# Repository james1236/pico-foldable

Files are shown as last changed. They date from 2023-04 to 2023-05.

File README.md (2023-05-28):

# pico-foldable
A small ds-style foldable Raspberry Pi Pico console with a buzzer, a joystick, a display and some buttons. You can easily make new games as seperate files in [/creations/](./creations) and a game picking menu/autorun system lets you play them (hold both buttons to get to the menu). The 3D printed case prints in 4 main parts and has a print-in-place hinge.

<p>
    
    
    
    
</p>

It is powered by a 3.7v LiPo battery through the adafruit Powerboost 500c recharger/power supply board. The EN (enable) pin on this board allows a circuit across the magnets between both displays to turn the whole device on when opened. A MicroUSB breakout board is installed to direct power to the Powerboost 500c while directing the data lines straight to the Pico's test pads, allowing you to plug it in as usual to upload code or debug.
  
  |  |   |
| ----- | ----- |
|     |  |





Printed using PLA on an Ender 3, 3D model [here](./complete%20pico%20foldable.stl). Inspired by <a href="https://www.youtube.com/watch?v=aZc5gUKcRZA">N-O-D-E</a>

### Parts
|Part|Quantity|
|---|---|
|Raspberry Pi Pico (RP2040)|1|
|Passive Piezo Electric Buzzer|1|
|<a href="https://www.adafruit.com/product/1944">Adafruit Powerboost 500C</a>|1|
|Female MicroUSB Breakout Board|1|
|520-614 Rainbow Ribbon Cable 10 Way (Squires Tools - conductor spacing 0.05in, conductor - 7/0.127mm tin plated copper, 1A 300V per conductor)|1|
|3mm dia x 1mm thick Neodynium magnets with 0.13kg pull|4|
|<a href="https://www.waveshare.com/1.5inch-OLED-Module.htm">1.5inch OLED Display Module, 128x128 Pixels, 16 Gray Scale, SPI/I2C Interface</a>|1|
|<a href="https://www.sparkfun.com/products/9426">Joystick - Sparkfun COM-09426</a>|1|
|Momentary Tactile PCB Push Buttons 6mm x 6mm|2|
|3.7V 500mAh Lipo Lithium Polymer Battery - GPS Drone EHAD702035 (Dimensions approx 37 mm x 21 mm x 8mm) |1|
|500 Ohm Resistor (for reducing buzzer volume)|1|

### Ribbon Cable Wires
|Num|Color|Connection|
|---|---|---|
|1|brown|bat 3.7|
|2|red|GND|
|3|orange|buzzer|
|4|yellow|left button|
|5|green|right button|
|6|blue|joystick X|
|7|purple|joystick Y|
|8|gray|VCC|

### Bottom Half Wires
|Output|Input|
|---|---|
|Magnet|GND (ribbon wire 2)|
|Left Button|GND (ribbon wire 2)|
|Right Button|GND (ribbon wire 2)|
|Joystick GND|GND (ribbon wire 2)|
|Buzzer -|GND (ribbon wire 2)|
|LiPo Battery negative (black) wire|GND (ribbon wire 2)|
|LiPo Battery positive (red) wire|bat 3.7 (ribbon wire 1)|
|Buzzer +|buzzer wire (ribbon wire 3)|
|Left Button (opposite half)|left button wire (ribbon wire 4)|
|Right Button (opposite half)|right button wire (ribbon wire 5)|
|Joystick X|joystick X wire (ribbon wire 6)|
|Joystick Y|joystick Y wire (ribbon wire 7)|
|Joystick VCC|VCC (ribbon wire 8)|

### Top Half Wires
|Output|Input|
|---|---|
|Powerboost 500c EN (enable)|Magnet|
|Powerboost 500c BAT|Battery positive (ribbon wire 1)|
|Powerboost 500c USB|USB Breakout VCC positive|
|Pico pin 28 (GND)|USB Breakout GND negative|
|Pico pin 40 (VBUS)|Powerboost 500c USB positive pad|
|Pico pin 33 (GND)|Powerboost 500c USB negative pad|
|Pico TP2 (Test pad 2)|USB Breakout Data Minus (DM or D-)|
|Pico TP3 (Test pad 3)|USB Breakout Data Plus (DP or D+)|
|Pico pin 13 (GND)|Bottom half GND (ribbon wire 2)|
|Pico pin 1 (GP0)|500 ohm resistor -> buzzer (ribbon wire 3)|
|Pico pin 19 (GP14)|Left button (ribbon wire 4)|
|Pico pin 20 (GP15)|Right button (ribbon wire 5)|
|Pico pin 31 (ADC0)|Joystick X (ribbon wire 6)|
|Pico pin 32 (ADC1)|Joystick Y (ribbon wire 7)|
|Pico pin 39 (VSYS)|VCC (ribbon wire 8)|
|Pico pin 21 (GP16)|Display SDA (DIN)|
|Pico pin 22 (GP17)|Display SCK (CLK)|
|Pico pin 36 (3V3 OUT)|Display VCC|
|Pico pin 18 (GND)|Display GND|

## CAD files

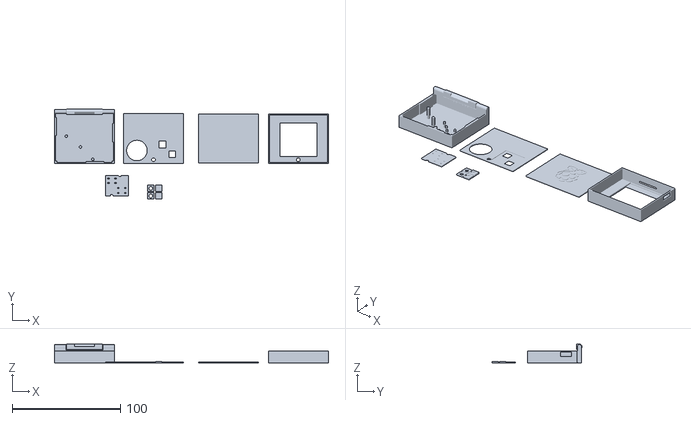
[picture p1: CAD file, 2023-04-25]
complete pico foldable.stl
253.6 x 83.5 x 17.5

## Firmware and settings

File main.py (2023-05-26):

# Initializes display and controls, shows menus
# Put .py files you want to run in /creations/ and they will show up in the menu
# Look at demo.py for an example of how to make a compatible creation

from machine import Pin, I2C, ADC

from time import sleep
import os
 
import framebuf

#TRUE = Throw all errors, crashes
#FALSE = Display errors on the device screen instead and attempt to continue
# Keep true while debugging to get info like line numbers
# Keep false for users so that one bug in a creation doesn't crash the whole device
debug = False

#Stop any previous music PWM
#from buzzer_music import music
#music().stop()


#Display wrapper class - better than display specific draw instructions...
class display:
    def __init__(self, display_type):
        self.display_type = display_type
        self.skippedFrames = 0
        
        if (self.display_type == "SSD1306 Monochrome"):
            width = 128
            height = 64

            #Put the GP pins you use for SDA and SCL here
            i2c = I2C(0,sda=Pin(4),scl=Pin(5),freq=600000) #40000
            from ssd1306 import SSD1306_I2C
            self.oled = SSD1306_I2C(width,height,i2c)

            self.width = self.oled.width
            self.height = self.oled.height
        
        elif (self.display_type == "Pimoroni Pico Display"):
            
            import picodisplay
            
            self.oled = picodisplay
            self.width = self.oled.get_width()
            self.height = self.oled.get_height()
            picodisplay_buffer = bytearray(self.width * self.height * 2)  # 2-bytes per pixel (RGB565)
            self.oled.init(picodisplay_buffer)
            picodisplay_buffer = None
            self.oled.set_backlight(1.0)
            self.fill(0)
            
        elif (self.display_type == "Waveshare SSD1327 16 Bit Grey"):
            
            from ssd1327 import WS_OLED_128X128
            
            oled_i2c = I2C(0, sda=Pin(16), scl=Pin(17),freq=3000000) #2300000
            self.oled = WS_OLED_128X128(oled_i2c, addr=int(hex(oled_i2c.scan()[0])))

            print("OLED I2C Address : " + hex(oled_i2c.scan()[0]).upper()) # Print the I2C device address in the command line
            print("OLED I2C Configuration: " + str(oled_i2c))
            
            self.width = self.oled.width
            self.height = self.oled.height
        
    def fill_rect(self, x, y, width, height, color):
        if (self.display_type == "SSD1306 Monochrome"):
            if (color > 0):
                color = 1
            self.oled.fill_rect(x,y,width,height,color)
            
        elif (self.display_type == "Pimoroni Pico Display"):
            c = round(255*color)
            self.oled.set_pen(c, c, c)
                
            self.oled.rectangle(x,y,width,height)
            
        elif (self.display_type == "Waveshare SSD1327 16 Bit Grey"):
            
            self.oled.fill_rect(x,y,width,height,round(15*color))
            
        else:
            #...since you can add support for other screens
            pass
        
    def show(self):
        if (self.display_type == "SSD1306 Monochrome" or self.display_type == "Waveshare SSD1327 16 Bit Grey"):
            try:
                self.oled.show()
            except OSError as e:
                self.skippedFrames = self.skippedFrames + 1
            
        elif (self.display_type == "Pimoroni Pico Display"):
            self.oled.update()
        
    def fill(self, color):
        if (self.display_type == "SSD1306 Monochrome"):
            if (color > 0):
                color = 1
            self.oled.fill(color)
        
        elif (self.display_type == "Pimoroni Pico Display"):
            c = round(255*color)
            self.oled.set_pen(c, c, c)
            
            self.oled.clear()
            
        elif (self.display_type == "Waveshare SSD1327 16 Bit Grey"):
            self.oled.fill(round(15*color))
            
    def text(self, text, x, y, color=1):
        if (self.display_type == "SSD1306 Monochrome"):
            self.oled.text(text, x, y)
            
        elif (self.display_type == "Pimoroni Pico Display"):
            c = round(255*color)
            self.oled.set_pen(c, c, c)
            
            self.oled.text(text, x, y, 0, 1)
            
        elif (self.display_type == "Waveshare SSD1327 16 Bit Grey"):
            self.oled.text(text, x, y, round(15*color))
    
    def pixel(self, x, y, color):
        if (self.display_type == "SSD1306 Monochrome"):
            if (color > 0):
                color = 1
                
            self.oled.pixel(x, y, color)
        
        elif (self.display_type == "Pimoroni Pico Display"):
            c = round(255*color)
            self.oled.set_pen(c, c, c)
            
            self.oled.pixel(x, y)
            
        elif (self.display_type == "Waveshare SSD1327 16 Bit Grey"):
            self.oled.pixel(x, y, round(15*color))
            
    def blit(self, buffer, x, y, key, palette=None):
        if (self.display_type == "SSD1306 Monochrome"):
            if (key > 0):
                key = 1
            self.oled.blit(buffer, x, y, key)
            
        elif (self.display_type == "Waveshare SSD1327 16 Bit Grey"):
            if (palette == None):
                self.oled.blit(buffer, x, y, round(15*key))
            else:
                self.oled.blit(buffer, x, y, round(15*key), palette)
            
    def line(self, x1, y1, x2, y2, color):
        if (self.display_type == "SSD1306 Monochrome"):
            if (color > 0):
                color = 1
            self.oled.line(x1, y1, x2, y2, color)
            
    def scroll(self, x, y):
        if (self.display_type == "SSD1306 Monochrome" or self.display_type == "Waveshare SSD1327 16 Bit Grey"):
            self.oled.scroll(x, y)

    def invert(self, i):
        self.oled.invert(i)
            
    def stroke_rect(self, x, y, width, height, color):
        if (self.display_type == "SSD1306 Monochrome"):
            if (color > 0):
                color = 1
            self.oled.stroke_rect(x,y,width,height,color)
            
        elif (self.display_type == "Pimoroni Pico Display"):
            c = round(255*color)
            self.oled.set_pen(c, c, c)
                
            self.oled.stroke_rect(x,y,width,height)
            
        elif (self.display_type == "Waveshare SSD1327 16 Bit Grey"):
            
            self.oled.stroke_rect(x,y,width,height,round(15*color))
        #self.fill_rect(0+x,0+y,width,1,color)
        #self.fill_rect(width-1+x,0+y,1,height,color)
        #self.fill_rect(0+x,height-1+y,width,1,color)
        #self.fill_rect(0+x,0+y,1,height,color)

    def ellipse(self, x, y, xr, yr, col, fill=False, quadrantBits=0xF):
        self.oled.ellipse(x, y, xr, yr, round(15*col), fill, quadrantBits)

    def poly(self, x, y, coords, col, fill=False):
        self.oled.poly(x, y, coords, round(15*col), fill)

    def rotate(self, rot):
        self.oled.rotate(rot)

    def contrast(self, c):
        self.oled.contrast(c)
    
    def poweron(self):
        self.oled.poweron()

    def poweroff(self):
        self.oled.poweroff()

#display = display("SSD1306 Monochrome")
#display = display("Pimoroni Pico Display") #WIP
display = display("Waveshare SSD1327 16 Bit Grey")

#Class for creations to use input
class controller:
    def __init__(self, analogs=[], buttons=[], joyscale=1000, deadzone=10, picodisplay=None):
        self.joystick = False
        self.joyscale = joyscale
        self.deadzone = deadzone
        
        if (len(analogs) >= 2):
            #Use analogs as joystick
            self.joyX = analogs[0]
            self.joyY = analogs[1]
            
            self.joystick = True
            self.joyCenter = (self.joyX.read_u16(),self.joyY.read_u16())
            
        self.buttons = buttons
        
        self.usePicodisplay = False
        if (not (picodisplay is None)):
            self.usePicodisplay = True
            self.picodisplay = picodisplay
            
            
    def readJoystick(self):
        if (self.joystick):
            x = self.joyX.read_u16() - self.joyCenter[0]
            y = self.joyY.read_u16() - self.joyCenter[1]
            
            x = x / self.joyscale
            y = y / self.joyscale
            
            outsideDeadzone = False
            if (abs(x) > self.deadzone or abs(y) > self.deadzone):
                outsideDeadzone = True
                
            return (-x, y, outsideDeadzone)
        
        else:
            #Emulate non existant joystick with buttons
            if (not self.readButton(0)):
                return (0, -20, True)
            elif (not self.readButton(1)):
                return (0, 20, True)
            elif (not self.readButton(2)):
                return (-20, 0, True)
            elif (not self.readButton(3)):
                return (20, 0, True)
            
            return (0,0,False)
    
    
    def readButton(self, buttonNumber):
        if (self.usePicodisplay):
            if (buttonNumber == 0):
                if (display.oled.is_pressed(display.oled.BUTTON_A)):
                    return True
                else:
                    return False
            
            elif (buttonNumber == 1):
                if (display.oled.is_pressed(display.oled.BUTTON_B)):
                    return True
                else:
                    return False
                
            elif (buttonNumber == 2):
                if (display.oled.is_pressed(display.oled.BUTTON_X)):
                    return True
                else:
                    return False
                
            elif (buttonNumber == 3):
                if (display.oled.is_pressed(display.oled.BUTTON_Y)):
                    return True
                else:
                    return False
        else:
            if (buttonNumber >= len(self.buttons)):
                return False
            return not self.buttons[buttonNumber].value()

controller = controller(analogs=[
    ADC(Pin(27)),
    ADC(Pin(26))
], buttons=[
    Pin(14, machine.Pin.IN, machine.Pin.PULL_UP),
    Pin(15, machine.Pin.IN, machine.Pin.PULL_UP)
])

#controller = controller(picodisplay=display)


creations = os.listdir('/creations/')

#Remove non .py files from creations array
i = 0
while (i < len(creations)):
    if (not (".py" in creations[i])):
        creations.pop(i)
    else:
        i = i + 1
    
creation = None

mainMenu = True
cursor = 0

frame = 0

names = []
thumbnails = []

#Get name+thumbnail for each creation
i = 0
for filename in creations:
    #Attempt Import
    exec("try:\n    from creations."+creations[i].replace('.py','')+" import description\nexcept ImportError:\n    pass")
    
    try:
        description
    except NameError:
        #Unsuccessful
        names.append(creations[i].replace('.py',''))
        thumbnails.append(None)
    else:
        #Successful
        if (hasattr(description, 'name')):
            names.append(description.name)
        else:
            names.append(creations[i].replace('.py',''))
            
        if (hasattr(description, 'thumbnail')):
            thumbnails.append(framebuf.FrameBuffer(description.thumbnail, 32, 32, framebuf.MONO_HLSB))
        else:
            thumbnails.append(None)
        
        del description
    i = i + 1


#Handle errors thrown by creations so that they can be dropped back to main menu
#Disable by setting debug = True
def errorHan(e, customMessage=None):
    global debug
    global mainMenu
    global creation
    global display
    
    if (debug):
        raise e
        return

    e = repr(e)
    print(e)
    print("Set debug = True in main.py to throw exceptions...")
    print("Skipped frames: " + str(display.skippedFrames))
    
    #Split exception string into screen width strings
    n = int(display.width/8)
    o = []
    while e:
        o.append(e[:n])
        e = e[n:]
    
    display.fill(0)
    for i in range(len(o)):
        display.text(o[i],0,i*8)
        
    if (not (customMessage is None)):
        o = []
        while customMessage:
            o.append(customMessage[:n])
            customMessage = customMessage[n:]
        
        for j in range(len(o)):
            display.text(o[j],0,((i+1)*8)+(j*8))
        
    display.show()
    sleep(5)
    creation = None
    mainMenu = True

#Function to load into the selected creation
def onSelect():
    global creations
    global cursor
    global creation
    global mainMenu
    global display
    global config
    
    print("onSelect")
    
    display.fill(0)
    display.text("Loading %s..." % creations[cursor].replace('.py',''), 0, 0)
    display.show()
    if (controller.readButton(0) == 1 and controller.readButton(1) == 1):
        return
    
    autorunFile = open('autorun', 'w')
    autorunFile.write(str(cursor))
    autorunFile.close()
    
    exec("try:\n    from creations.%s import creation\nexcept Exception:\n    pass" % creations[cursor].replace('.py',''))
    
    mainMenu = False
    try:
        creation = creation(display, controller)
    except Exception as e:
        errorHan(e, "Error while trying to create object from expected 'creation' class in the file")
    
#Try to auto open previous creation
autorunFile = open('autorun', 'r')
c = autorunFile.read()
if (not (c == '')):
    cursor = int(c)
    if (cursor >= len(creations)):
        cursor = len(creations)-1
    onSelect()
autorunFile.close()

moveCooldown = 0

buttonCooldowns = [0,0]
buttonCooldown = 5

heldDown = 0

led = Pin(25, Pin.OUT) #Blink led to show it's alive

display.contrast(255)

while True:
    frame = frame + 1
    led.toggle()
    
    buttonCooldowns[0] = max(0, (buttonCooldowns[0] - 1))
    buttonCooldowns[1] = max(0, (buttonCooldowns[1] - 1))
    
    #Hold down both buttons for 30 frames to exit to main menu
    if (controller.readButton(0) and controller.readButton(1)):
        heldDown = heldDown + 1
        if (heldDown > 30):
            heldDown = 0
            buttonCooldowns[0] = 15
            buttonCooldowns[1] = 15
            print("Skipped frames: " + str(display.skippedFrames))
            
            if (not(creation is None)):
                try:
                    creation.close()
                except Exception:
                    pass
                del creation
                creation = None
            mainMenu = True
            autorunFile = open('autorun', 'w')
            autorunFile.write(str(""))
            autorunFile.close()
                
    else:
        heldDown = 0
    
    if (mainMenu):
        #Move cursor
        if (moveCooldown > 0):
            moveCooldown = moveCooldown - 1
        
        joy = controller.readJoystick()
        if (joy[2] and (moveCooldown <= 0) and (abs(joy[1]) > abs(joy[0]))):
            moveCooldown = 5
            if (joy[1] > 0):
                #up
                cursor = cursor + 1
                if (cursor >= len(creations)):
                    cursor = 0
            else:
                #down
                cursor = cursor - 1
                if (0 > cursor):
                    cursor = len(creations)-1
            
        #Detect button press
        select = False
        if (buttonCooldowns[0] == 0):
            if (controller.readButton(0)):
                buttonCooldowns[0] = buttonCooldown
                select = True
        
        display.fill(0)
        if (not (thumbnails[cursor] is None)):
            for thumbx in range(5):
                for thumby in range(5):
                    #display.blit(thumbnails[cursor],display.width-40,16,0)
                    display.blit(thumbnails[cursor],-32 + thumbx*32 + (frame % 32),-32 + thumby*32 + (frame % 32),0)
        
        #List files in creations folder
        ySpacing = 11
        i = 0
        
        #Calculate scroll position of text
        linesPerScreen = 11
        scroll = 0
        if (len(creations) > linesPerScreen):
            if (cursor > 2):
                scroll = (cursor-2)*ySpacing
                
                #Stop scroll at the bottom
                if ((len(creations)-1) - cursor < 3):
                    scroll = (len(creations)-linesPerScreen)*ySpacing
        
        scroll = 0 - scroll

            
        for i in range(len(creations)):
            display.fill_rect(8,3+(ySpacing*i)-1+scroll,len(names[i])*8+2,ySpacing,0)
            display.text(names[i],9,3+(ySpacing*i)+scroll)
            
            #Selection Border
            if (cursor == i):
                display.stroke_rect(8,3+(ySpacing*i)-1+scroll,len(names[i])*8+2,ySpacing,1)
            
            i = i + 1
        
            
        #Scroll bar
        display.stroke_rect(0,0,4,display.height,1)
        
        position = cursor/max((len(creations)-1),1)
        display.fill_rect(1,round(position*display.height)-round(display.height/8),2,round(display.height/4),1)
                
        display.show()
        
        if (select):
            onSelect()
        
    else:
        #Run loaded creation
        try:
            creation.tick()
        except Exception as e:
            errorHan(e)

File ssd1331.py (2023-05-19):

import ustruct
import utime
from micropython import const

_DRAWLINE = const(0x21)
_DRAWRECT = const(0x22)
_NO_SCROLL = const(0x2e)
_FILL = const(0x26)
_PHASEPERIOD = const(0x12)
_SETCOLUMN = const(0x15)
_SETROW = const(0x75)
_CONTRASTA = const(0x81)
_CONTRASTB = const(0x82)
_CONTRASTC = const(0x83)
_MASTERCURRENT = const(0x87)
_SETREMAP = const(0xA0)
_STARTLINE = const(0xA1)
_DISPLAYOFFSET = const(0xA2)
_NORMALDISPLAY = const(0xA4)
_DISPLAYALLON = const(0xA5)
_DISPLAYALLOFF = const(0xA6)
_INVERTDISPLAY = const(0xA7)
_SETMULTIPLEX = const(0xA8)
_SETMASTER = const(0xAD)
_DISPLAYOFF = const(0xAE)
_DISPLAYON = const(0xAF)
_POWERMODE = const(0xB0)
_PRECHARGE = const(0xB1)
_CLOCKDIV = const(0xB3)
_PRECHARGEA = const(0x8A)
_PRECHARGEB = const(0x8B)
_PRECHARGEC = const(0x8C)
_PRECHARGELEVEL = const(0xBB)
_VCOMH = const(0xBE)
_LOCK = const(0xfd)


class SSD1331:

    _INIT = (
        (_DISPLAYOFF, b''),
        (_LOCK, b'\x0b'),
        (_SETREMAP, b'\x72'), # RGB Color
        (_STARTLINE, b'\x00'),
        (_DISPLAYOFFSET, b'\x00'),
        (_NORMALDISPLAY, b''),
        (_PHASEPERIOD, b'\x31'),
        (_SETMULTIPLEX, b'\x3f'),
        (_SETMASTER, b'\x8e'),
        (_POWERMODE,b'\x0b'),
        (_PRECHARGE, b'\x31'), #;//0x1F - 0x31
        (_CLOCKDIV, b'\xf0'),
        (_VCOMH, b'\x3e'), #;//0x3E - 0x3F
        (_MASTERCURRENT, b'\x0c'), # ;//0x06 - 0x0F
        (_PRECHARGEA, b'\x64'),
        (_PRECHARGEB, b'\x78'),
        (_PRECHARGEC, b'\x64'),
        (_PRECHARGELEVEL, b'\x3a'), # 0x3A - 0x00
        (_CONTRASTA, b'\x91'), #//0xEF - 0x91
        (_CONTRASTB, b'\x50'), #;//0x11 - 0x50
        (_CONTRASTC, b'\x7d'), #;//0x48 - 0x7D
        (_NO_SCROLL, b''),
        (_DISPLAYON, b'')
    )
    _ENCODE_PIXEL = ">H"
    _ENCODE_POS = ">BB"
    _ENCODE_LINE = ">BBBBBBB"
    _ENCODE_RECT = ">BBBBBBBBBB"

    def line(self,x1,y1,x2,y2,color):
        r= (color >> 10) & 0x3e
        g= (color >> 5) & 0x3e
        b= (color & 0x1f) << 1
        data =ustruct.pack(self._ENCODE_LINE,x1,y1,x2,y2,r,g,b)
        self._write(_DRAWLINE,data)

    def rectangle(self,x,y,width,height,linecolor,fillcolor):
        if fillcolor is None:
          self._write(_FILL,b'\x00')
          br = 0
          bg = 0
          bb = 0
        else:
          self._write(_FILL,b'\x01')
          br= (fillcolor >> 10) & 0x3e
          bg= (fillcolor >> 5) & 0x3e
          bb= (fillcolor & 0x1f) << 1
        r= (linecolor >> 10) & 0x3e
        g= (linecolor >> 5) & 0x3e
        b= (linecolor & 0x1f) << 1
        data = ustruct.pack(self._ENCODE_RECT,x,y,x+width-1,y+height-1,r,g,b,br,bg,bb)
        self._write(_DRAWRECT,data)


    def fill(self,color=0):
        self.rectangle(0,0,self.width,self.height,color,color)


    def __init__(self, spi, dc, cs, rst=None, width=96, height=64):
        self.spi=spi
        self.dc = dc
        self.cs = cs
        self.rst = rst
        self.width = width
        self.height = height
        self.reset()
        for command,data in self._INIT:
           self._write(command,data)
        self.font = None

    def _write(self, command=None, data=None):
        if command is None:
            self.dc.value(1)
        else:
            self.dc.value(0)
        self.cs.value(0)
        if command is not None:
            self.spi.write(bytearray([command]))
        if data is not None:
            self.spi.write(data)
        self.cs.value(1)


    def _read(self, command=None, count=0):
        self.dc.value(0)
        self.cs.value(0)
        if command is not None:
            self.spi.write(bytearray([command]))
        if count:
            data = self.spi.read(count)
        self.cs.value(1)
        return data


    def color565(self,r, g, b):
        #  5  4  3  2  1  0  9  8  7  6  5  4  3  2  1  0
        #  R4 R3 R2 R1 R0 G5 G4 G3 G2 G1 G0 B4 B3 B2 B1 B0
        # return  (r & 0xf8) << 8 | (g & 0xfc) << 3 | b >> 3
        
        #  for ARM need  to swap byte
        #  G2 G1 G0 B4 B3 B2 B1 B0 R4 R3 R2 R1 R0 G5 G4 G3
        return  (g & 0x1C) << 1 | (b >> 3) | (r & 0xf8) | g >> 5


    def pixel(self, x , y , color=None):
        """ set pixel position """
        self._write(_SETCOLUMN,bytearray([x,x]))
        self._write(_SETROW,bytearray([y,y]))

        if color is None:
          """ read pixel """
          return self._read(None,2)
        else:
#          self._write(None,bytearray([color >> 8, color &0xff]))
          self.line(x,y,x,y,color)

    def block(self, x,y,width,height, data):
        self._write(_SETCOLUMN, bytearray([x,x+width-1]))
        self._write(_SETROW,bytearray([y,y+height-1]))
        self._write(None,data)

    def reset(self):
      if self.rst is not None:
         self.rst.value(0)
         utime.sleep(0.1)
         self.rst.value(1)

    def setFont(self,font):
      self.font= font

    def putChar (self,x,y, utf8Char, color):
       #print("putChar(x={},y={},c={},color={})".format(x,y,utf8Char,color))
       if self.font is None:
          return x
    # {offset, width, height, advance cursor, x offset, y offset} */
       self.font.setPosition(utf8Char)
       _offset,_width,_height,_cursor,x_off,y_off =  self.font.current_glyph
       #print("_offset",_offset)
       #print("Width",_width)
       #print("height",_height)
       #print("cursor",_cursor)
       #print("xoff",x_off)
       #print("yoff",y_off)
       for y1 in range(_height):
         for x1 in range(_width):
              if self.font.getNext():
                 self.pixel(x+x1+x_off,y+y1+y_off,color)
       return x+_cursor

    def putText(self,x,y,txt,color):
      if not self.font is None:
        for  c in txt:
          x = self.putChar(x,y,c,color)
          
          
if __name__ == "__main__":
    from machine import Pin, SPI
    spi = SPI(0,baudrate=10000000,sck=Pin(6),mosi=Pin(7))
    dc=Pin(2,Pin.OUT)
    cs=Pin(3,Pin.OUT)
    oled = SSD1331(spi=spi,dc=Pin(2),cs=Pin(3))
    oled.fill(0)

    import framebuf
    buffer = bytearray(oled.width * oled.height * 2)
    fb = framebuf.FrameBuffer(buffer,
                              oled.width,
                              oled.height,
                              framebuf.RGB565)

    #test frame buffer
    colors = []
    for i in range(8):
        r = (i & 1) * 255
        g = ((i >> 1)  & 1)  * 255
        b = ((i >> 2) & 1 ) * 255
        colors.append(oled.color565(r,g,b))
            
    while True:
        for color in colors:
            fb.fill(color)
            oled.block(0,0,96,64,buffer)
            utime.sleep(1)
        

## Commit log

2021-02-26 Added error handling, button for main menu, improvements to everything
    [buzzer_music.py, demo.py, main.py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]
2021-04-03 Added full support for WS_OLED128x128 SSD1327 display and WIP support for pimironi pico display.
2023-04-25 Add models
    [complete pico foldable.stl, pico ds 10.stl]
2023-04-25 Redundant model
    [pico ds 10.stl]
2023-05-10 Add ribbon cable wiring
2023-05-14 Update wiring
2023-05-16 Update ribbon wiring
2023-05-16 Update ribbon cable wiring
2023-05-20 Finish wiring writeup, add detailed description
2023-05-24 Update spaceout and display driver functions
2023-05-26 Improve ribbon cable description
2023-05-26 Improve battery description
2023-05-28 Correction on ADC wiring
2023-05-28 Create wiring schematic
2023-05-28 Create schematic (svg)
2023-05-28 Add wiring schematic to README
